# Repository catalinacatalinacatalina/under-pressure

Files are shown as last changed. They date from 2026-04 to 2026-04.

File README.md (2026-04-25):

# Under Pressure - Analog Distortion Pedal

A complete documentation of designing and building an analog distortion pedal for electric guitars, based on Brian Wampler's minimal parts-count circuit design.

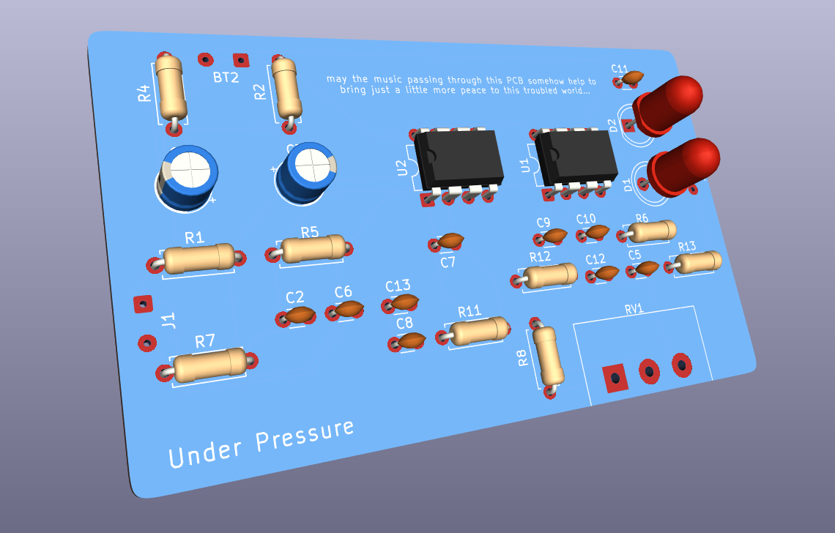
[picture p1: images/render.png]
Under Pressure PCB render


### 🎵 About the Name

**Under Pressure** is named after the iconic 1981 song by David Bowie & Queen. The name captures the essence of what a distortion pedal does: it takes the natural dynamics of a guitar signal and compresses it under intense pressure, forcing it through clipping stages that create the characteristic aggressive and driven tone.

## 🎯 Project Overview

This project is divided into **three distinct phases**, each with its own workflow and deliverables:

1. **Phase 01: Breadboard Prototype** - Testing and validation on solderless breadboard
2. **Phase 02: PCB Design** - Professional PCB layout and manufacturing
3. **Phase 03: PCB Soldering** - Attaching the components to the designed PCB

## ✅ Current Build Status

- **Breadboard Prototype**: Complete and working with guitar + amp validation.
- **PCB Design**: Complete (layout, DRC, Gerbers, and drill files generated).
- **Manufacturer Order**: Pending submission.

## 📐 Circuit Architecture

- ⚡ **Stage 1**: 9V battery with virtual ground (Vref) biasing
- 📈 **Stage 2**: implements two gain stages with clipping diodes to shape the distortion character
- 🎚️ **Stage 3**: provides final amplification with impedance buffering for clean output

## 📂 Project Structure

```
├── docs/              # Design documentation & notes
├── hardware/          # Circuit & PCB files
│   ├── breadboard/    # Phase 01: Prototype testing
│   ├── components/    # Datasheets & BOM
│   ├── pcb/           # Phase 02: PCB design & Gerber files
│   └── schematics/    # KiCad schematics
├── simulations/       # SPICE circuit analysis
├── audio/             # Test recordings
└── images/            # Build photos & diagrams
```

## 🚀 Quick Start

### For Breadboard (Phase 01)

1. Understand the schematics
2. Buy the needed components
3. Replicate the circuit on a breadboard
4. Plug your guitar, test audio and tone
5. Confirm ready for PCB

### For PCB Design (Phase 02)

1. Use KiCad (9.0) to create schematics
2. Design PCB layout
3. Generate Gerber files
4. Run final DRC/ERC checks
5. Place order with PCB manufacturer

### For PCB Soldering (Phase 03)
...

## 📚 Documentation Roadmap

```
PHASE 01: Breadboard                    PHASE 02: PCB Design                    PHASE 03: PCB Soldering
├── ✅ Understand circuit               ├── ✅ Verify breadboard values         ├── ⏳ Prepare soldering tools
├── ✅ Source components                ├── ✅ Create schematic in KiCad        ├── ⏳ Solder components
├── ✅ Build on breadboard              ├── ✅ Design PCB layout                ├── ⏳ Inspect solder joints
├── ✅ Test audio and tone              ├── ✅ Run design rule check (DRC)      └── ⏳ Test PCB functionality
├── ✅ Document final values            ├── ✅ Generate Gerber files
└── ✅ Confirm ready for PCB            └── ⏳ Order PCB
```

## 🔗 References

- **Main Tutorial**: [How to Design a Basic Distortion Pedal Circuit](https://www.wamplerpedals.com/blog/lifestyle-hobby/2024/08/how-to-design-a-basic-distortion-pedal-circuit/) - Brian Wampler
- **Main Component Sourcing**: Electronica Embajadores - https://www.electronicaembajadores.com/es/

## 📊 Project Status

| Phase | Status | Progress |
|---|---|---|
| Phase 01: Breadboard | ✅ Done | Fully working and validated |
| Phase 02: PCB Design | ✅ Done | Designed and ready for manufacturer order |
| Phase 03: PCB Soldering | ⏳ Pending | Waiting for manufactured PCB delivery |

## 🛠️ Tools Needed

**Phase 01 (Breadboard)**:
- Solderless breadboard
- Multimeter (for voltage/continuity testing)
- Wires
- Guitar & amplifier (for audio testing)

**Phase 02 (PCB Design)**:
- KiCad
- Gerber viewer (integrated in KiCad)
- PCB manufacturer (JLCPCB, PCBWay, Elecrow, etc.)

**Phase 03 (PCB Soldering)**:
- Soldering iron
- Lead-free solder (0.8-1.0mm)
- Solder sucker or desoldering wick
- Brass cleaner or damp sponge
- Helping hands tool

---

**Last Updated**: April 25, 2026 | **Design Based On**: Wampler Basic Distortion Circuit (Aug 2024) | **Build Status**: Breadboard complete, PCB designed, pending manufacturer order

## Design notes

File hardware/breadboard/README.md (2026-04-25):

# Breadboard Prototype

Current status: Breadboard build is complete and working.

## Validation Summary

- Power stage tested at 9V with stable virtual ground (Vref).
- Input and gain response verified.
- Clipping stage verified with smooth distortion behavior.
- Audio output tested with guitar and amplifier.

## Next Step

- PCB design is already finished.
- Pending action: submit fabrication files to the selected PCB manufacturer.

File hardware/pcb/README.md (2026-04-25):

# PCB Design Process in KiCad

This is the workflow I followed to go from breadboard prototype to a finished pedal PCB.

Current status: Steps 1 to 5 are complete (schematic, layout, routing, and fabrication files). The PCB order is still pending submission to the manufacturer.

## 1. Create the Schematic in KiCad

1. Open the project in the **Schematic Editor**.
2. Place symbols for all components (op-amp, resistors, capacitors, diodes, jacks, power, etc.).
3. Connect nets with clear labels (`IN`, `OUT`, `GND`, `V+`, etc.).
4. Assign footprints to each symbol using **Tools > Assign Footprints**.
5. Run **ERC (Electrical Rules Check)** and fix important warnings.

Expected result: a clean schematic with no critical errors and all footprints assigned.

> You may notice you cannot find the VCC and GND pins for the TL072 op-amp. If that happens, add another TL072 symbol **with the same reference name** and set it to Unit C. Pins 4 and 8 will appear there. You can see this in the stages schematic.

## 2. Move to the PCB Editor

1. Open the **PCB Editor**.
2. Use **Tools > Update PCB from Schematic** to import the netlist and components.
3. Define the board outline on the `Edge.Cuts` layer.
4. Configure basic design rules: minimum track width, minimum clearance...

## 3. Place Components

1. Place mechanical parts first (jacks, potentiometers, switch, LED, connectors) based on enclosure and ergonomics.
2. Group components by functional blocks (power stage, core, and gain).
3. Keep sensitive signal paths short and separate high-impedance audio nodes where possible.
4. Leave enough room for routing and ground areas.

## 4. Route Traces

1. Route critical lines first (input, feedback, and audio output).
2. Route power and ground after that.
3. Use a ground plane when it helps reduce noise.
4. Avoid unnecessary crossings, very long traces on sensitive nodes, and awkward angles.
5. Run **DRC (Design Rules Check)** to verify everything and fix errors.

Routing example:

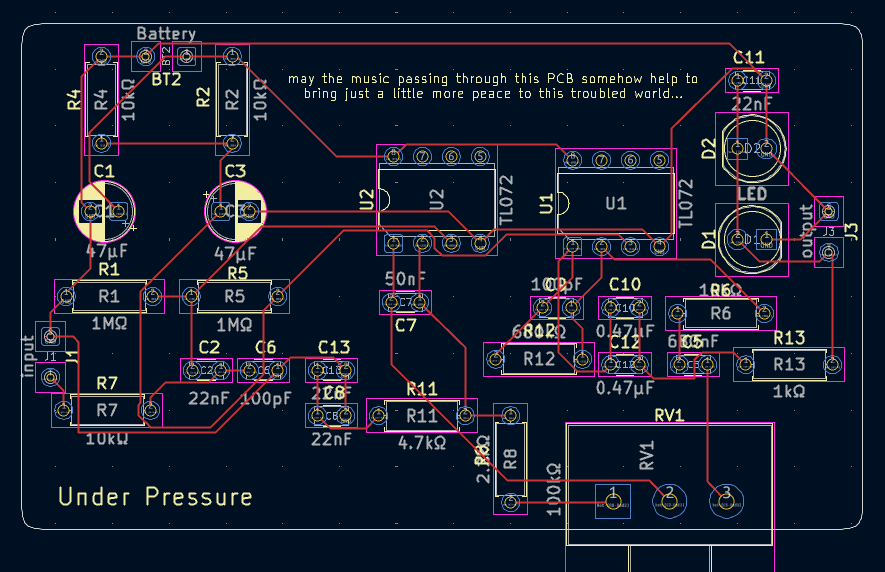
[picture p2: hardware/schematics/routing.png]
PCB routing


## 5. Generate Gerbers and Drill Files

1. In PCB Editor, open **File > Plot**.
2. Generate the required Gerber layers (copper, solder mask, silkscreen, board outline, etc.).
3. Generate drill files with **Generate Drill Files** (`.drl` PTH and NPTH).
4. Verify everything with a Gerber viewer before sending to manufacturing.
5. Save the final fabrication package in the project output folder (for example, `hardware/pcb/gerbers`).

## Rendered View

PCB render

## 6. Send to Manufacturing (Pending)

Choose your preferred PCB manufacturer and place the order.

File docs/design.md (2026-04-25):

# Under Pressure - Circuit Design

## Overview

This is a minimal-parts-count analog distortion circuit based on Brian Wampler's design. The circuit was first built and validated on breadboard, then converted into a PCB design.

## Current Project Status

- Breadboard prototype is working and validated.
- PCB design is complete.
- PCB manufacturing order is pending.

**Note**: This simplified version **excludes the passive tone control stage** for minimal component count. It includes only power supply, two gain stages with clipping, and an output buffer.

## Circuit Architecture

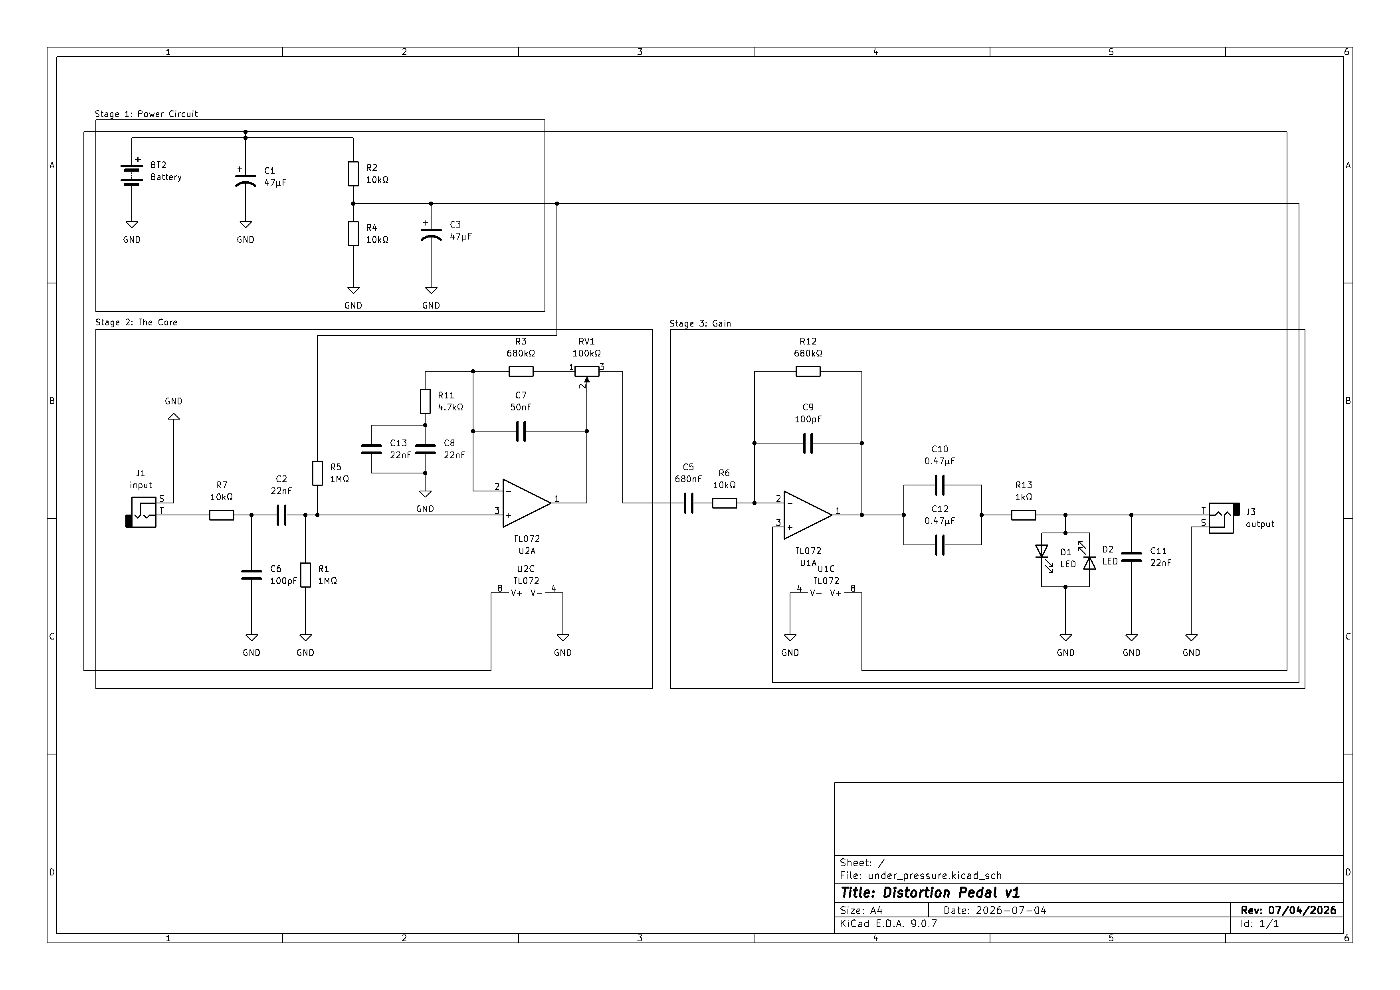
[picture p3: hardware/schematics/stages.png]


The circuit consists of three main stages: the **Power Supply** stage provides DC power to all circuit components, the **Distortion Core** implements two gain stages with clipping diodes to shape the distortion character, and the **Output Buffer** provides final amplification with impedance buffering for clean output.

The intersection in all three stages is **vref** in the original schematic.

## Component List

### Breadboard Phase
| Component | Value | Qty |
|---|---|-----|
| **OPERATIONAL AMPLIFIERS** | | |
| TL072 Operational Amplifier | - | 2 |
| **CAPACITORS** | | |
| Radial Electrolytic Capacitor | 47µF | 2 |
| Ceramic Disc Capacitor | 100pF | 2 |
| Ceramic Disc Capacitor | 22nF | 4 | 
| Ceramic Disc Capacitor | 47pF | 1 | 
| X7R Multilayer Ceramic Capacitor | 680nF | 1 | 
| Tantalum Electrolytic Capacitor | 0.47µF | 2 | 
| **RESISTORS AND POTENTIOMETERS** | | |
| Carbon Film Resistor 1/4W | 10KΩ | 1 | 
| Carbon Film Resistor 1/4W | 1KΩ | 1 | 
| Carbon Film Resistor 1/2W | 1MΩ | 1 | 
| Carbon Film Resistor 1/2W | 2.2KΩ | 1 | 
| Carbon Film Resistor 1/2W | 4.7KΩ | 1 | 
| Carbon Film Resistor 1/2W | 680KΩ | 1 |
| Potentiometer | 100KΩ Linear | 1 |
| **POWER SUPPLY** | | |
| Panasonic 9V Alkaline Battery | - | 1 |
| 9V Battery Holder with Wire | - | 1 | 
| **INPUT/OUTPUT** | | |
| 5mm Red Diffuse LED | - | 2 |
| Female Jack Connector | - | 2 | 

### PCB Phase
It is hardly recommended in terms of space to use PCB components, but in order to maintain simplicity I am using the same components from the breadboard phase. Keep this in mind if you use the KiCad files or if you manufacture this PCB.

## Modifications from Wampler's Original
1. This version excludes stage IV for simplicity.
2. Small changes in capacitors due to the lack of capacitors when buyed

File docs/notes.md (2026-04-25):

# Project Notes

## Current Status

- Breadboard prototype is fully working and validated.
- PCB design is complete and fabrication files are generated.
- PCB order is pending submission to the manufacturer.

## Design Phase

- **Reference**: Brian Wampler - Basic Distortion Circuit Tutorial (Aug 2024)
- **Design Approach**: Breadboard first, then PCB if satisfied with tone
- **Result**: Breadboard tone validated, then moved to PCB design stage.

## Breadboard Build Checklist

### Pre-Build
- [x] All components sourced
- [x] Breadboard layout sketched
- [x] Power supply tested (should output 9V)
- [x] Multimeter available for testing

### Power Supply Stage
- [x] 9V battery or regulated supply connected
- [x] Vref (virtual ground) at approximately 4.5V
- [x] Decoupling capacitors placed
- [x] No voltage drops on ground rail

### Input Stage
- [x] Input capacitor functional
- [x] Gain potentiometer responds smoothly
- [x] Signal amplification confirmed
- [x] No oscillation

### Inverting Stage with Clipping
- [x] Diodes installed (start with LEDs)
- [x] Clipping threshold achievable
- [x] Distortion is smooth, not harsh
- [x] Low-pass filter in place

## PCB Readiness Checklist

- [x] Schematic and footprints finalized in KiCad
- [x] PCB layout completed
- [x] DRC completed with no blocking errors
- [x] Gerber and drill files generated
- [ ] PCB order submitted to manufacturer

## References

- **Main Tutorial**: https://www.wamplerpedals.com/blog/lifestyle-hobby/2024/08/how-to-design-a-basic-distortion-pedal-circuit/
- **Parts bought at**: https://www.electronicaembajadores.com/es/

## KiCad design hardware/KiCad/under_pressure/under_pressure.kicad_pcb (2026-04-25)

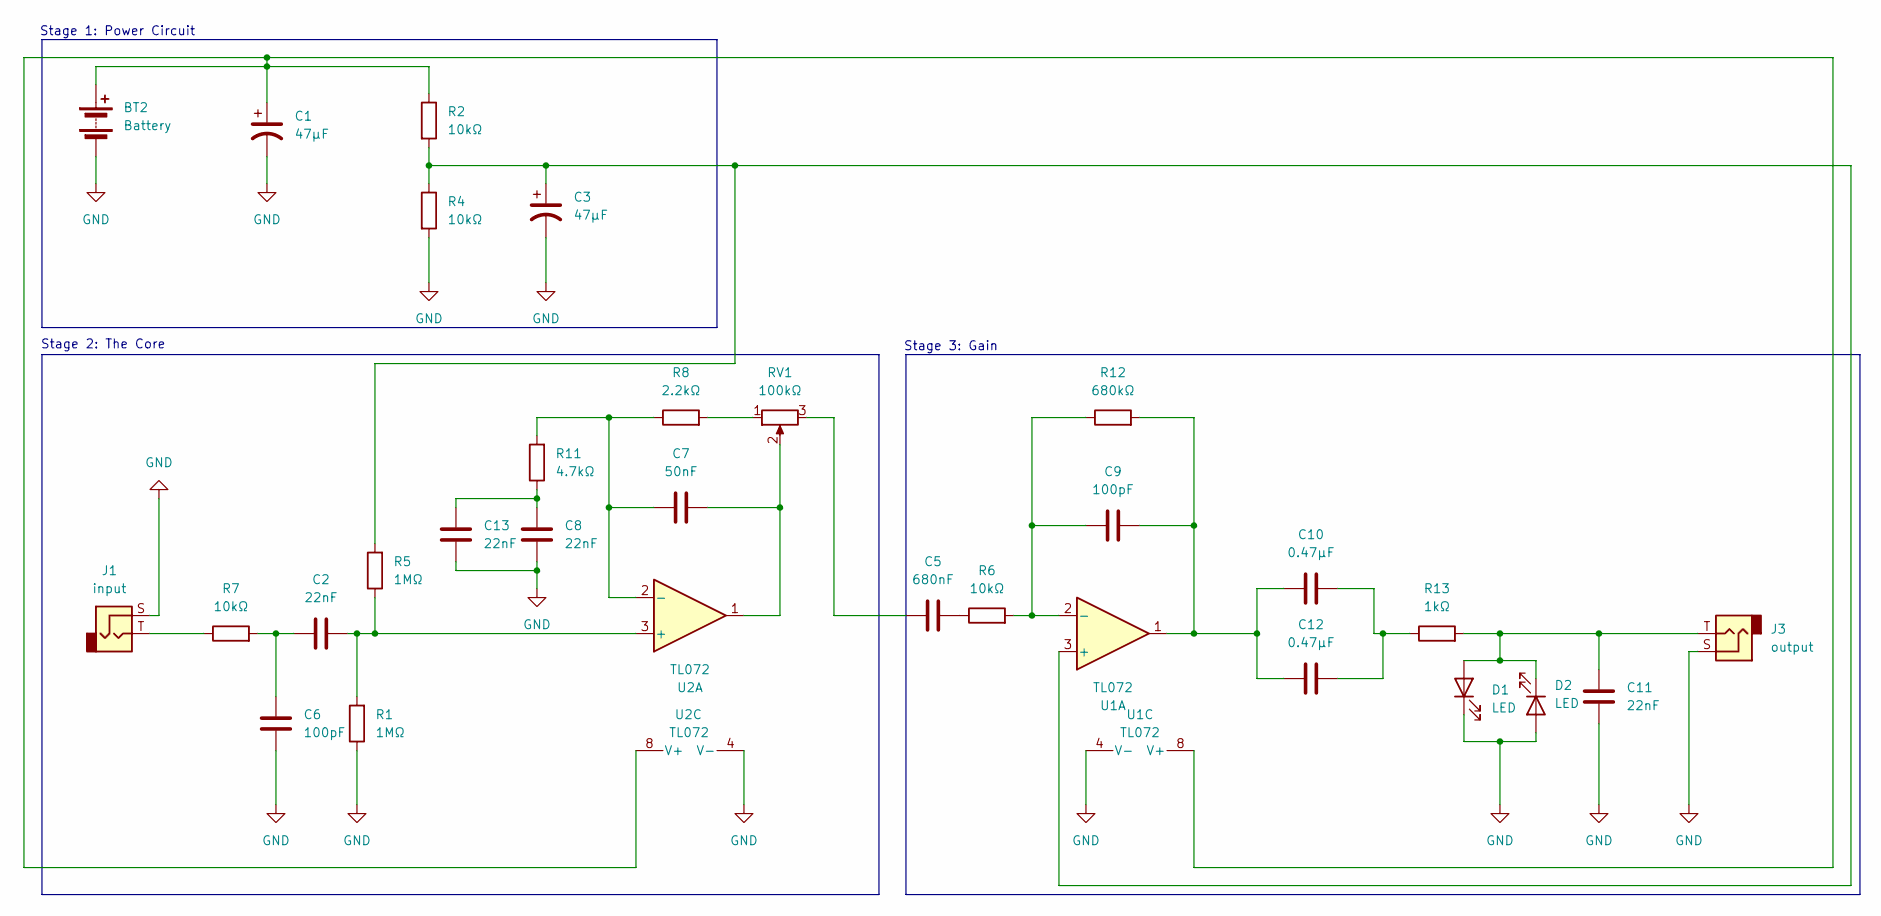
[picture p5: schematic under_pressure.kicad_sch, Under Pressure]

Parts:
BT2: Battery; SolderWire-0.1sqmm_1x02_P3.6mm_D0.4mm_OD1mm
C1, C3: 47µF; CP_Radial_D5.0mm_P2.50mm
C2, C8, C11, C13: 22nF; C_Disc_D3.0mm_W1.6mm_P2.50mm
C5: 680nF; C_Disc_D3.0mm_W1.6mm_P2.50mm
C6, C9: 100pF; C_Disc_D3.0mm_W1.6mm_P2.50mm
C7: 50nF; C_Disc_D3.0mm_W1.6mm_P2.50mm
C10, C12: 0.47µF; C_Disc_D3.0mm_W1.6mm_P2.50mm
D1, D2: LED; LED_D5.0mm
J1: input; SolderWire-0.1sqmm_1x02_P3.6mm_D0.4mm_OD1mm
J3: output; SolderWire-0.1sqmm_1x02_P3.6mm_D0.4mm_OD1mm
R1, R5: 1MΩ; R_Axial_DIN0207_L6.3mm_D2.5mm_P7.62mm_Horizontal
R2, R4, R6, R7: 10kΩ; R_Axial_DIN0207_L6.3mm_D2.5mm_P7.62mm_Horizontal
R8: 2.2kΩ; R_Axial_DIN0207_L6.3mm_D2.5mm_P7.62mm_Horizontal
R11: 4.7kΩ; R_Axial_DIN0207_L6.3mm_D2.5mm_P7.62mm_Horizontal
R12: 680kΩ; R_Axial_DIN0207_L6.3mm_D2.5mm_P7.62mm_Horizontal
R13: 1kΩ; R_Axial_DIN0207_L6.3mm_D2.5mm_P7.62mm_Horizontal
RV1: 100kΩ; Potentiometer_Alps_RK163_Single_Horizontal
U1: TL072
U2: TL072; DIP-8_W7.62mm

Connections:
GND: BT2.2 (-), C1.2, C3.2, C6.1, C8.2, C11.2, C13.2, D1.1 (K), D2.2 (A), J1.S, J3.S, R1.1, R4.2, U1.4 (V-), U2.4 (V-)
unnamed: BT2.1 (+), C1.1, R2.1, U1.8 (V+), U2.8 (V+)
unnamed: C2.1, C6.2, R7.2
unnamed: C5.1, RV1.3
unnamed: C5.2, R6.1
unnamed: C7.2, RV1.2, U2.1
unnamed: C9.2, C10.1, C12.1, R12.2, U1.1
unnamed: C10.2, C12.2, R13.1
unnamed: C8.1, C13.1, R11.1
unnamed: C11.1, D1.2 (A), D2.1 (K), J3.T, R13.2
unnamed: J1.T, R7.1
unnamed: R8.2, RV1.1
unnamed: C3.1, R2.2, R4.1, R5.2, U1.3 (+)
unnamed: C9.1, R6.2, R12.1, U1.2 (-)
unnamed: C2.2, R1.2, R5.1, U2.3 (+)
unnamed: C7.1, R8.1, R11.2, U2.2 (-)

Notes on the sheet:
Stage 2: The Core
Stage 3: Gain
Stage 1: Power Circuit

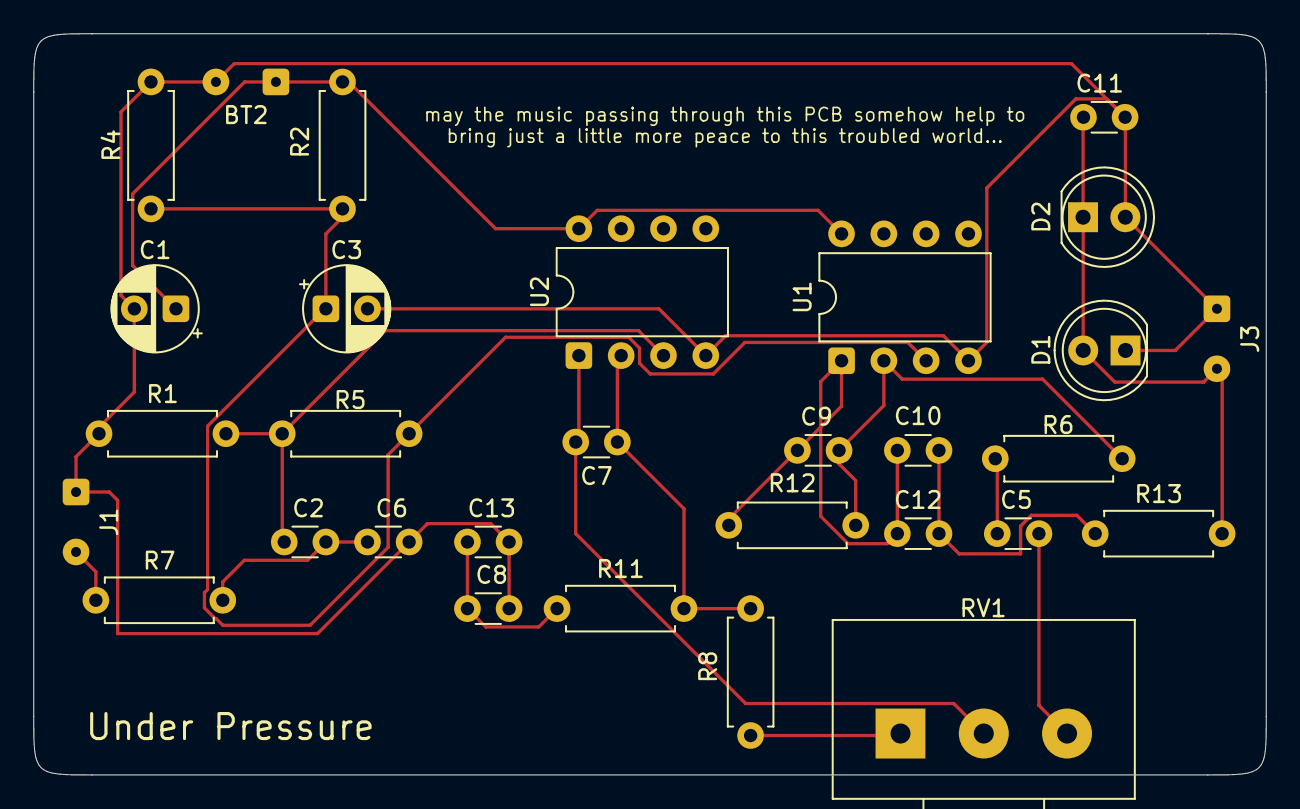
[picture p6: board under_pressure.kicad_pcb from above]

Board: 2 copper layers, 74.0 x 44.5 mm, 30 parts (0 on the bottom side), 16 nets.

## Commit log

2026-04-07 Doc: Add PCB soldering phase and schematics
2026-04-09 Update hardware schematic images
2026-04-17 archivos kicad
    [under_pressure.kicad_pcb, under_pressure.kicad_sch]
2026-04-18 cableado + esquematico arreglado
    [under_pressure.kicad_pcb, under_pressure.kicad_sch]
2026-04-25 Update docs about project current status
